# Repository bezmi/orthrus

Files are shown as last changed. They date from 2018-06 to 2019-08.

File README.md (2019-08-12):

# orthrus
56 key wireless split keyboard running on QMK. Staggered orthogonal layout

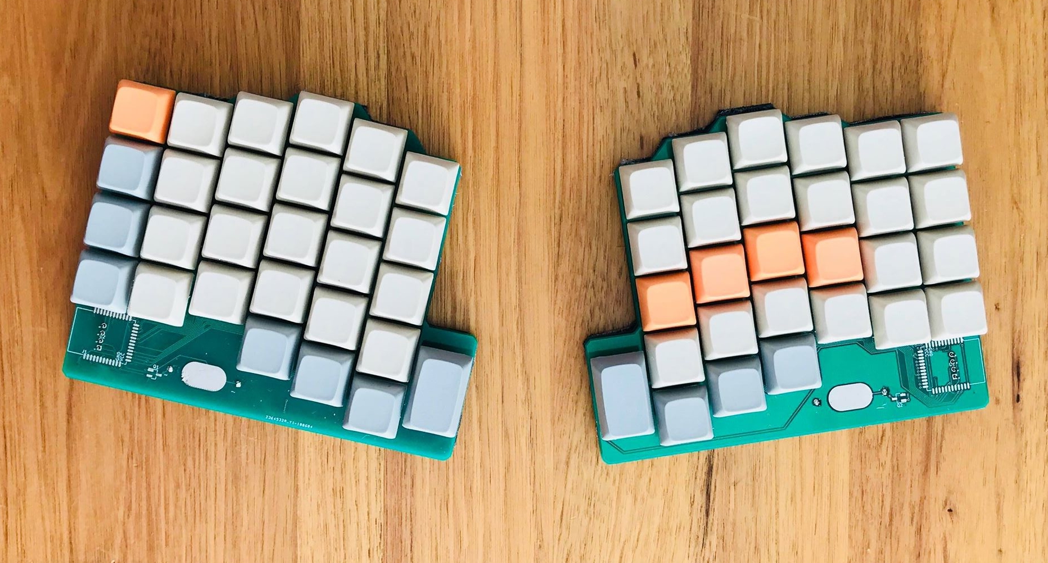
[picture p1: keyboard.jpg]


Refer to individual folders for help on the build, raise an issue if you need any extra help :)

To use with qmk, just merge the qmk_firmware/ directory in this repository with your downloaded qmk_firmware directory

# UPDATES

Over the time that I have been using this keyboard, the "sandwich" style battery holder has bee less than ideal. I have modified my keyboard with [these battery holders](https://au.rs-online.com/web/p/battery-holders-mounts/7188457/), which are epoxied to the top PCB for each half. The negative terminal of the battery holder is soldered to pad 3 "GND_P" on the top PCB with a short wire:

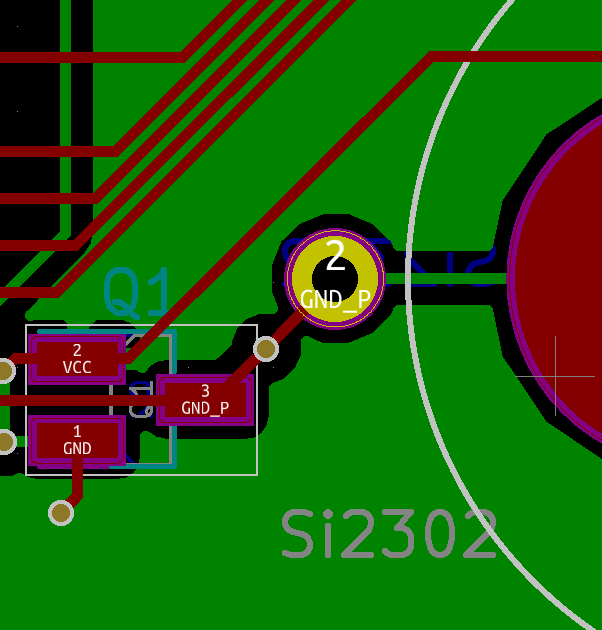
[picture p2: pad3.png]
Negative Terminal


The positive terminal is soldered to the through-hole VCC connection with a short wire:

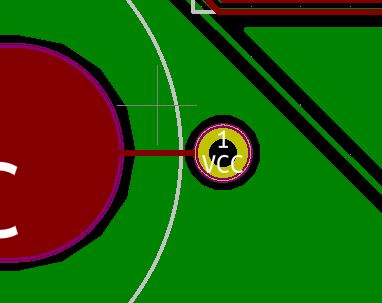
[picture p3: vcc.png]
Positive Terminal


This is what it looks like now.

Current image

# Acknowledgements
Thanks to [@reversebias](https://github.com/reversebias) for the inspiration as well as the firmware to make this work and [@joric](https://github.com/joric) for making the firmware work with the cheaper nrf modules

Thanks to technomancy for the original 42 key [atreus](https://atreus.technomancy.us) design and profet for the [atreus62](http://shop.profetkeyboards.com/product/atreus62-keyboard) design that I have been using for quite a while.

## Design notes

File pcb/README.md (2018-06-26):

# PCB

PCB design files and gerbers for the orthrus keyboard. See the [mitosis build log](https://imgur.com/a/mwTFj#JtzXTCD) for an overview of how to put this together.

There are a couple of minor differences. For example, for the programming header, my right angle connector footprint is too far in from the edge of the PCB, which resulted in the particular right angle headers I had not being reachable. I compromised by just using straight headers that go through the holes in the top (switch plate) pcb. It works just fine and the header is optional anyway. You could just as well solder temporary wires, program, then desolder before final assembly.

For the foam base, I did not have access to a lasercutter, so I cut a cloth mouse pad to size (including a cutout for the module on the bottom), cut all of the switch pins flush to the bottom of the PCB and hot glued the mousepad bits to the bottom. It is a little bumpy if you feel the bottom of the keyboard, but the typing feel is not compromised. Make sure you put tape on the module to avoid shorts!

For the receiver, I use the [mitosis receiver PCB](https://github.com/reversebias/mitosis-hardware). You can look at the BOM there (adjusting for extra switches, etc). I designed the PCBs to use the cheaper black nrf modules from aliexpress (Yj-14015), which are slightly smaller than the official waveshare module. For the receiver I had a legitimate waveshare module (blue) laying around, so I just used that, but soldering a Yj-14015 module to the receiver PCB can be very tricky. Feel free to extend the mitosis receiver pads and submit a pull request.

Make sure the PCB fab house can do 0.8mm slots. I've got mine manufactured from JLCPCB and the PCBs came out perfect.

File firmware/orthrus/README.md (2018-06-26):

# Mitosis Keyboard Firmware

This branch adds YJ-14015 and IAR support.

mitosis-mjt (https://www.youtube.com/watch?v=hMlQvZNmCc8)

It also makes use of the keyswitch board LED (it blinks two times on powering up to indicate that firmware works).

I'm using [modified QMK firmware](https://github.com/joric/qmk_firmware/blob/mitosis-joric/keyboards/mitosis/mitosis.c) (with mitosis-MJT keymap) that adds LED startup sequence to the receiver as well.

## Hardware

* [ST-LINK/V2](http://www.ebay.com/itm/ST-Link-V2-Programming-Unit-mini-STM8-STM32-Emulator-Downloader-M89-Top-/331803020521) (OpenOCD-compatible debugger/programmer)
* [YJ-14015](https://www.aliexpress.com/item/Core51822-BLE-4-0-Bluetooth-2-4G-Wireless-Module-NRF51822-Antenna-Board-For-ULP-SPI-I2C/32832872640.html) (nRF51822-module, 32-bit ARM Cortex M0, 128kB flash + 32kB RAM)
* PCB gerbers I used in this build: https://github.com/reversebias/mitosis-hardware

I've also collected a few Kicad ports from Altium: https://github.com/joric/mitosis-hardware/tree/joric_kicad

## Software

* [IAR 7.50.2 for ARM](https://www.iar.com/) (IDE that includes a C/C++ compiler)
* [nRF5_SDK_11](https://developer.nordicsemi.com/nRF5_SDK/) (nRF51/52 toolchain)
* [OpenOCD g73b676c](http://www.freddiechopin.info/en/download/category/10-openocd-dev/) (embedded debugger for Windows 10)
* [WinAVR 20100110](https://sourceforge.net/projects/winavr/) (firmware tools for AVR MCU)

## IAR support

Original build used blue Waveshare Core51822 (B)
modules ([$6.99](http://www.waveshare.com/core51822-b.htm)), but aliexpress has slightly smaller black YJ-14015
modules that are also much cheaper (about $3.50), you can find them on Aliexpress or [eBay](http://www.ebay.com/itm/BLE4-0-Bluetooth-2-4GHz-Wireless-Module-NRF51822-Board-Core51822-B-/282575577879).
It seems like stock firmware that works on Core51822 (B), doesn't work on YJ-14015 at all (update, already works, see https://github.com/reversebias/mitosis/pull/7).
You can build a working firmware in IAR, using provided project (open .eww, run build, that's all).
You may also use precompiled firmware from the `precompiled_iar` folder.

## GCC support

This repository now supports GCC for YJ-14015 as well, so there's no need for IAR.
Use GCC-prebuild firmware from the precompiled folder or apply this diff https://github.com/reversebias/mitosis/pull/7
(update: it's already merged into upstream).

## nRF51 Firmware

This firmware is used for the nRF51 modules on the keyboard halves and the receiver.

### Precompiled nRF51 Firmware

This precompiled firmware features YJ-14015 support and status LEDs support.

* left half: [precompiled-basic-left.hex](https://raw.githubusercontent.com/joric/mitosis/devel/precompiled_iar/precompiled-basic-left.hex)
* right half: [precompiled-basic-right.hex](https://raw.githubusercontent.com/joric/mitosis/devel/precompiled_iar/precompiled-basic-right.hex)
* receiver: [precompiled-basic-receiver.hex](https://raw.githubusercontent.com/joric/mitosis/devel/precompiled_iar/precompiled-basic-receiver.hex)

### Uploading nRF51 Firmware

To flash nRF modules, connect ST-LINK/V2 to the module programming pins (SWCLK, SWDIO, GND, 3.3V - top to bottom) and run this batch (windows 10):

```
@echo off
set path=C:\SDK\openocd-0.10.0-dev-00247-g73b676c\bin-x64;%path%
set file=%~dp0custom\iar\_build\nrf51822_xxac.hex
openocd ^
-f interface/stlink-v2.cfg ^
-f target/nrf51.cfg ^
-c init ^
-c "reset halt" ^
-c "flash write_image erase %file:\=/%" ^
-c "reset" ^
-c exit

```

### Building nRF51 Firmware

I am using Windows 10 and Windows Subsystem for Linux (WSL) for everything.

Building nRF firmware with GCC:

```
cd nRF5_SDK_11
git clone https://github.com/joric/mitosis
sudo apt install openocd gcc-arm-none-eabi
(edit /components/toolchain/gcc/Makefile.posix, set GNU_INSTALL_ROOT := /usr/)
sudo cp mitosis/49-stlinkv2.rules /etc/udev/rules.d/
cd mitosis
git checkout devel
cd mitosis-keyboard-basic/custom/armgcc
make

```

## QMK Firmware

This firmware is used for the Arduino Pro Micro on the keyboard receiver.

### Precompiled QMK Firmware

First of all, check [QMK repository](https://github.com/qmk/qmk_firmware/tree/master/keyboards/mitosis/keymaps) maybe your keymap is already merged.

* mitosis-default (original) from /u/reverse_bias: [kle](http://www.keyboard-layout-editor.com/#/gists/f89d2ff79b72e920939b), [keymap.c](https://github.com/qmk/qmk_firmware/blob/master/keyboards/mitosis/keymaps/default/keymap.c), [firmware](https://raw.githubusercontent.com/joric/qmk_firmware/mitosis-joric/precompiled/mitosis_default.hex), [pic](http://i.imgur.com/Ioh0Iix.png)
* mitosis-qwerty (qwerty layout) from /u/runninghack: [kle](http://www.keyboard-layout-editor.com/#/gists/acec41432b5ce0eb341d88245a20d9da), [keymap.c](https://github.com/runninghack/qmk_firmware/blob/master/keyboards/mitosis/keymaps/qwerty/keymap.c), [firmware](https://raw.githubusercontent.com/joric/qmk_firmware/mitosis-joric/precompiled/mitosis_qwerty.hex), [pic](https://i.imgur.com/Jt0lTWt.png)
* mitosis-mjt (qwerty layout) from /u/kaybeerry: [kle](http://www.keyboard-layout-editor.com/#/gists/e213fec721cb035614cef401cd6750d6), [keymap.c](https://github.com/mterhar/qmk_firmware/blob/master/keyboards/mitosis/keymaps/mjt/keymap.c), [firmware](https://raw.githubusercontent.com/joric/qmk_firmware/mitosis-joric/precompiled/mitosis_mjt.hex), [pic](https://i.imgur.com/BiKsnIV.png)
* mitosis-carvac_dv (qwerty layout) by /u/Carvac: [keymap.c](https://github.com/CarVac/qmk_firmware/blob/master/keyboards/mitosis/keymaps/carvac_dv/keymap.c)
* mitosis-workman (workman layout) by /u/mloffer: [kle](http://www.keyboard-layout-editor.com/#/gists/db73d647ad8a67c9654a4daeab0e0873), [keymap.c](https://github.com/mloffer/mitosis-workman)
* mitosis-atreus (atreus layout) from /u/iamjoric: [kle](http://www.keyboard-layout-editor.com/#/gists/e1b26b86c4e024d2f4f3185e5b769a00), [keymap.c](https://github.com/joric/qmk_firmware/blob/mitosis-joric/keyboards/mitosis/keymaps/atreus/keymap.c), [firmware](https://raw.githubusercontent.com/joric/qmk_firmware/mitosis-joric/precompiled/mitosis_atreus.hex)
* mitosis-joric (experimental) from /u/iamjoric: [kle](http://www.keyboard-layout-editor.com/#/gists/3f5dd1c848bb9a7a723161ad5e0c8e39), [keymap.c](https://github.com/joric/qmk_firmware/blob/mitosis-joric/keyboards/mitosis/keymaps/joric/keymap.c), [firmware](https://raw.githubusercontent.com/joric/qmk_firmware/mitosis-joric/precompiled/mitosis_joric.hex)

### Uploading QMK Firmware

To flash prebuilt QMK firmware on Pro Micro, press reset button on the receiver and run the script below.
You can look up the bootloader port in device manager (e.g. COM9), it shows only for a few seconds after reset.

```
set path=C:\WinAVR-20100110\bin;%path%
avrdude -p atmega32u4 -P COM9 -c avr109  -U flash:w:mitosis_default.hex
```

### Building QMK firmware:

```
sudo apt-get install gcc-avr avr-libc
cd qmk_firmware
make mitosis-default
```

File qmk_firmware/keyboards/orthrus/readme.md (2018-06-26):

Orthrus
=======

Keyboard Maintainer: [@bezmi](https://github.com/bezmi)
Hardware Supported: [Orthrus PCB](https://github.com/bezmi/orthrus)

Make example for this keyboard (run from root qmk_firmware directory)

    make orthrus:default:avrdude

See [build environment setup](https://docs.qmk.fm/build_environment_setup.html) then the [make instructions](https://docs.qmk.fm/make_instructions.html) for more information.

## Orthrus Notes

Files based off of the Mitosis keyboard. Uses a pro micro along with receiver PCB for wireless functionality.

Keyboard PCB design files can be found [here](https://github.com/bezmi/orthrus)
Receiver PCB is straight from the [mitosis](https://github.com/reversebias/mitosis-hardware)

Firmware for the nordic MCUs can be found [here](https://github.com/bezmi/orthrus)

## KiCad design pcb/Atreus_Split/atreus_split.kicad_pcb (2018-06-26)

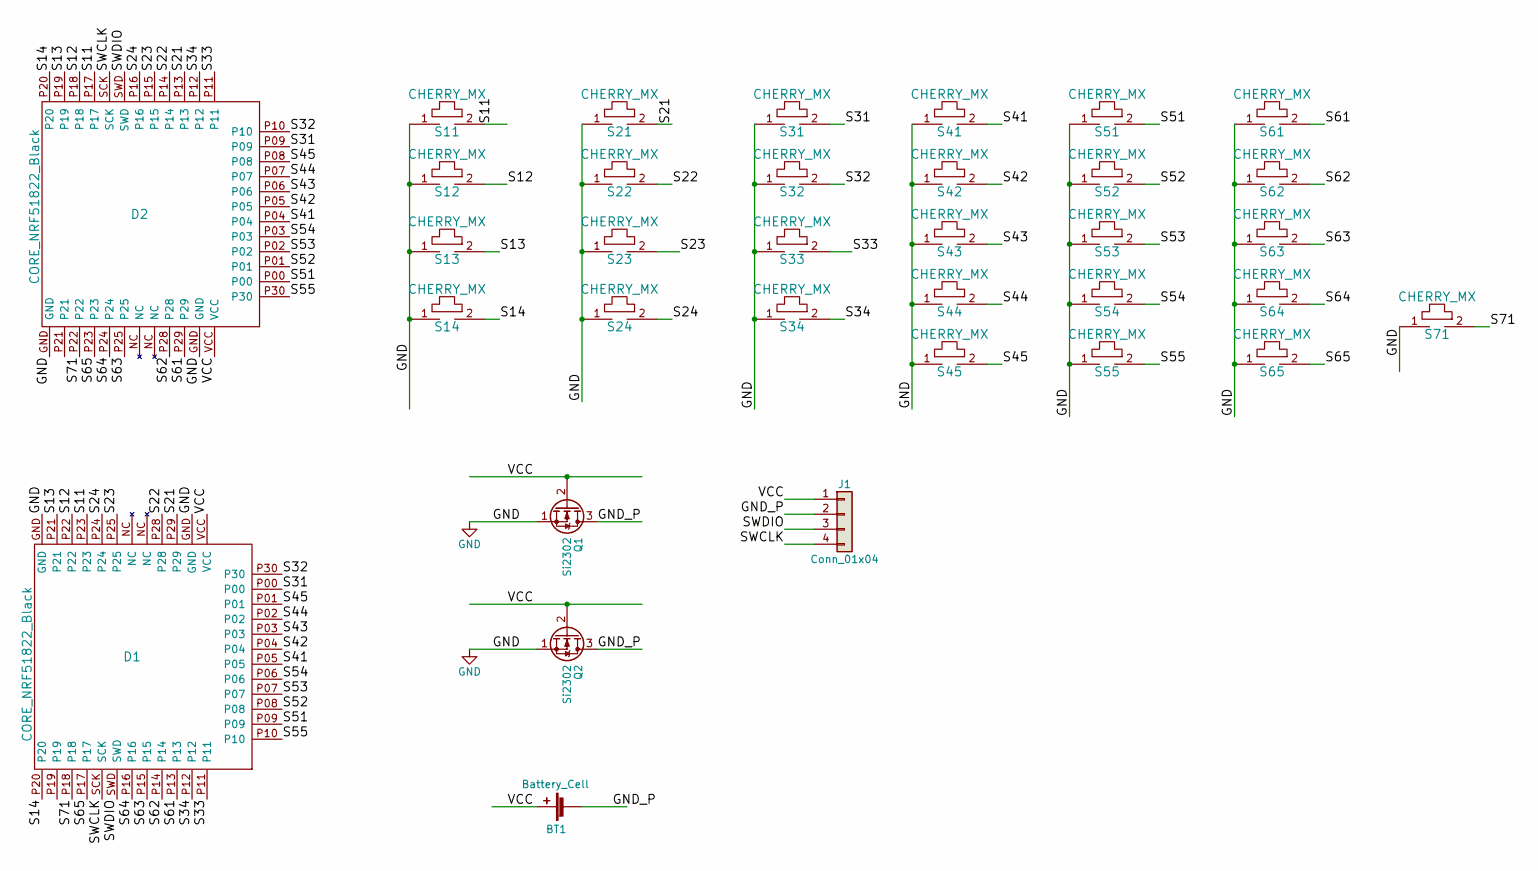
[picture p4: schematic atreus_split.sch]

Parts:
BT1: Battery_Cell; CR2032_pad
D1, D2: CORE_NRF51822_Black
J1: Conn_01x04; Pin_Header_Angled_1x04_Pitch2.54mm
Q1, Q2: Si2302; SI2302
S11, S12, S13, S14, S21, S22, S23, S24, S31, S32, S33, S34, S41, S42, S43, S44, S45, S51, S52, S53, S54, S55, S61, S62, S63, S64, S65, S71: CHERRY_MX; cherry

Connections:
/GND_P: BT1.2 (-), J1.2, Q1.3 (D), Q2.3 (D)
/S11: D1.P23, D2.P17, S11.2
/S12: D1.P22, D2.P18, S12.2
/S13: D1.P21, D2.P19, S13.2
/S14: D1.P20, D2.P20, S14.2
/S21: D1.P29, D2.P13, S21.2
/S22: D1.P28, D2.P14, S22.2
/S23: D1.P25, D2.P15, S23.2
/S24: D1.P24, D2.P16, S24.2
/S31: D1.P00, D2.P09, S31.2
/S32: D1.P30, D2.P10, S32.2
/S33: D1.P11, D2.P11, S33.2
/S34: D1.P12, D2.P12, S34.2
/S41: D1.P05, D2.P04, S41.2
/S42: D1.P04, D2.P05, S42.2
/S43: D1.P03, D2.P06, S43.2
/S44: D1.P02, D2.P07, S44.2
/S45: D1.P01, D2.P08, S45.2
/S51: D1.P09, D2.P00, S51.2
/S52: D1.P08, D2.P01, S52.2
/S53: D1.P07, D2.P02, S53.2
/S54: D1.P06, D2.P03, S54.2
/S55: D1.P10, D2.P30, S55.2
/S61: D1.P13, D2.P29, S61.2
/S62: D1.P14, D2.P28, S62.2
/S63: D1.P15, D2.P25, S63.2
/S64: D1.P16, D2.P24, S64.2
/S65: D1.P17, D2.P23, S65.2
/S71: D1.P18, D2.P22, S71.2
/SWCLK: D1.SCK, D2.SCK, J1.4
/SWDIO: D1.SWD, D2.SWD, J1.3
/VCC: BT1.1 (+), D1.VCC, D2.VCC, J1.1, Q1.2 (G), Q2.2 (G)
GND: D1.GND, D2.GND, Q1.1 (S), Q2.1 (S), S11.1, S12.1, S13.1, S14.1, S21.1, S22.1, S23.1, S24.1, S31.1, S32.1, S33.1, S34.1, S41.1, S42.1, S43.1, S44.1, S45.1, S51.1, S52.1, S53.1, S54.1, S55.1, S61.1, S62.1, S63.1, S64.1, S65.1, S71.1

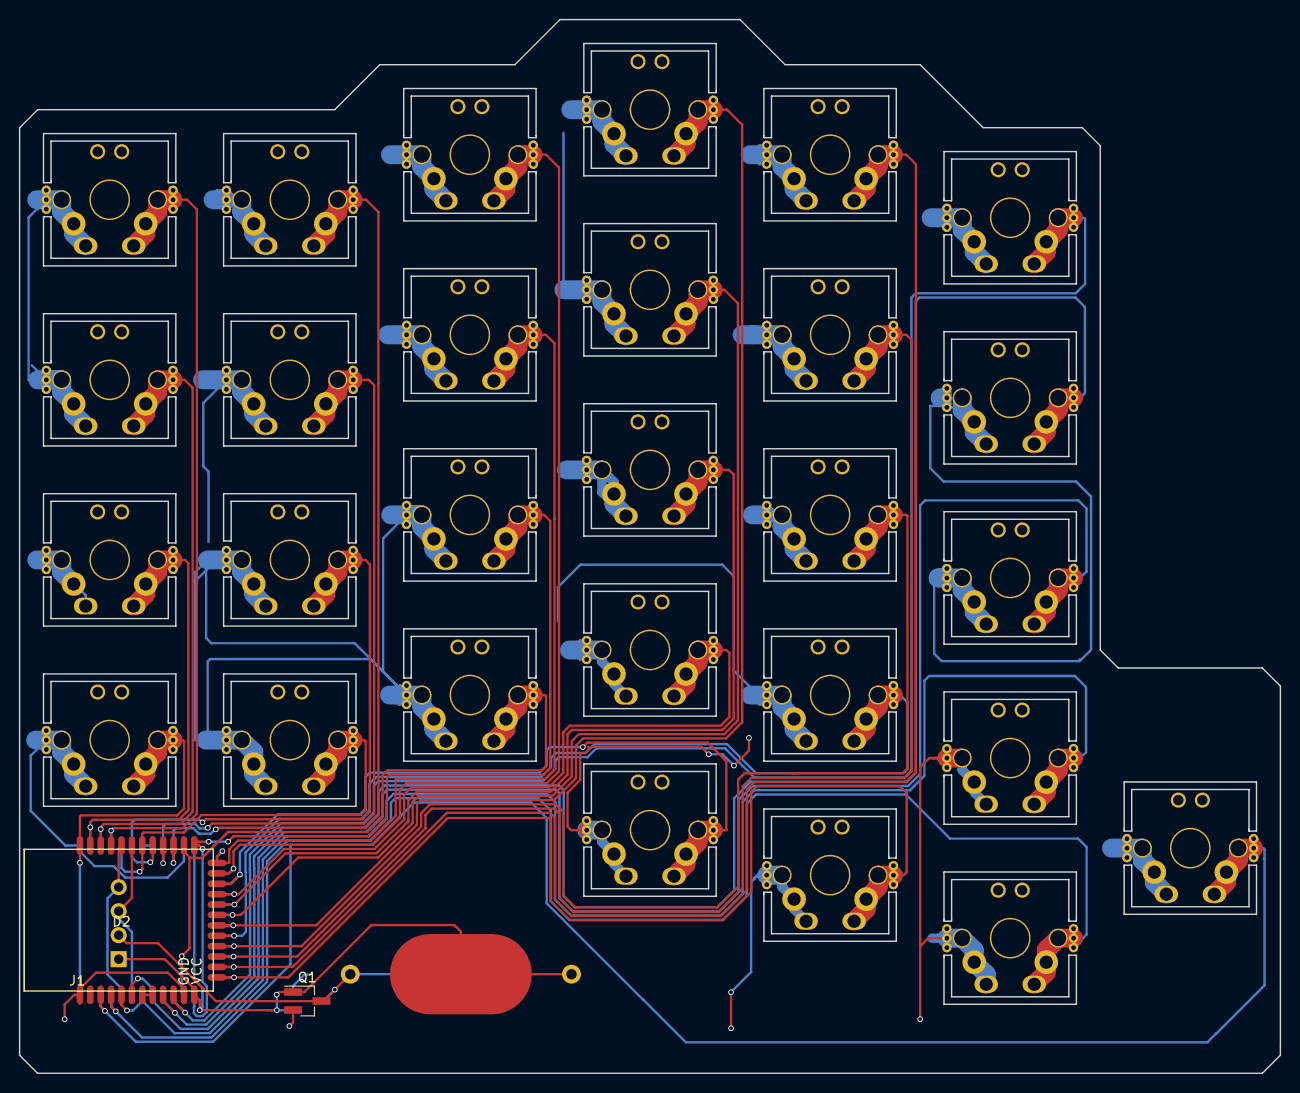
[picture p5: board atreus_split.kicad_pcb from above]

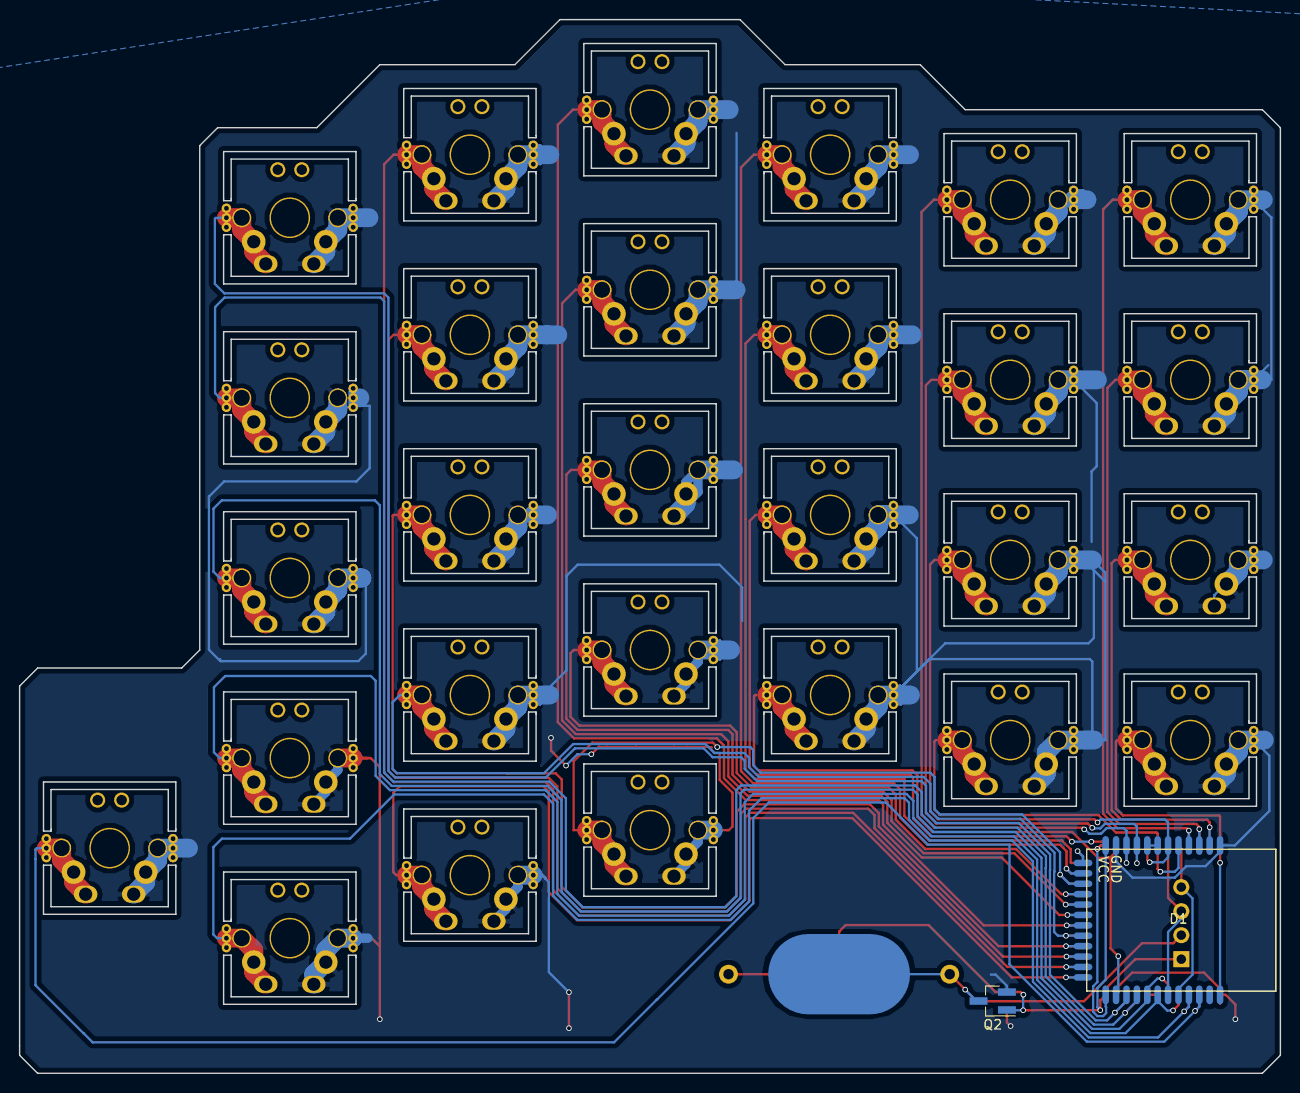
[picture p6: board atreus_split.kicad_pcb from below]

Board: 2 copper layers, 133.4 x 111.4 mm, 34 parts (2 on the bottom side), 33 nets.

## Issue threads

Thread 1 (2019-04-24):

ST-Link V2 programmer shuts off when attaching to keyboard PCB

Peping, 2019-04-24:
**CONTENT WARNING: copious amounts of rosin in pics below**
First of all, thanks for making this keyboard available. It's been an amazing, albeit very long journey getting all parts and fitting everything together.

However I got stuck trying to program the keyboard PCBs. Whenever I try to connect my ST-Link V2 to the header, it just shuts off as if it had come across a short or something.

Now I have practically no knowledge of electronics, but I have tested for shorts between all the header pins and there isn't one. I then tried to test for continuity between header ground and Yj-14015 module ground, I got some voltage drop, but still continuity. I suspect the voltage drop is due to the transistor and is normal.

Speaking of, you moved the FET slightly as opposed to Mitosis, which raises my doubts about whether I soldered it on the right side. Could you check my photos? Could you please also check for anything I might've missed that could cause my programmer to freak out?

All photos are of the to-be right half of the keyboard:
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

__________________________________
For right angle headers I instead used straight headers and connected them via a solder bridge

bezmi, 2019-04-26:
That is exactly how I have the FET soldered, so I am not sure what is causing your issue. You can try desoldering the FET and bridging the bottom left (source) and right (drain) pad - here is the [pinout](https://www.datasheetq.com/image/MCC/607347.gif). This should bypass the reverse polarity protection and allow you to power the module directly. Make sure you only apply the 3.3V.

You can also try some continuity checking. In a [reverse polarity protection circuit](url) with an n-channel FET, the negative of the battery should be connected to the drain, the ground of the circuit (GND pin on module) should be connected to the source and the gate should be connected to both the positive terminal of the battery and the VCC pin on the module.

Peping, 2019-04-26:
Thanks for the tip. I will try bridging the pads. Jut a quick question: Do I have to have the battery connected in order to connect the programmer?

bezmi, 2019-04-26:
No, leave the battery disconnected and power it via the 3.3V on the programmer. The pinout of the header from bottom to top is:

1. 3.3V
2. GND
3. SWDIO
4. SWCLK

Peping, 2019-04-28:
Bridging the pads made it so that the programmer's indicator (the blue LED) would stay on. Before, it would turn of the moment I connected GND and VDD. But with the bridged FET pads, as you suggested, I still couldn't connect to the chip via OCD.
```
Open On-Chip Debugger 0.10.0
Licensed under GNU GPL v2
For bug reports, read
	http://openocd.org/doc/doxygen/bugs.html
Info : The selected transport took over low-level target control. The results might differ compared to plain JTAG/SWD
adapter speed: 1000 kHz
Info : Unable to match requested speed 1000 kHz, using 950 kHz
Info : Unable to match requested speed 1000 kHz, using 950 kHz
Info : clock speed 950 kHz
Info : STLINK v2 JTAG v17 API v2 SWIM v4 VID 0x0483 PID 0x3748
Info : using stlink api v2
Info : Target voltage: 3.211556
Error: init mode failed (unable to connect to the target)
in procedure 'init'
in procedure 'ocd_bouncer'
```

In a desperate attempt involving lots of continuity checking and misinterpreting the results, I left the FET pads unconnected. Strapping the programmer to the board in this state (no FET, no bridge, nothing) allowed OpenOCD to connect, or at least that's what I thought. When I tried flashing it, it failed.

```
Open On-Chip Debugger 0.10.0
Licensed under GNU GPL v2
For bug reports, read
	http://openocd.org/doc/doxygen/bugs.html
Info : The selected transport took over low-level target control. The results might differ compared to plain JTAG/SWD
adapter speed: 1000 kHz
Info : Unable to match requested speed 1000 kHz, using 950 kHz
Info : Unable to match requested speed 1000 kHz, using 950 kHz
Info : clock speed 950 kHz
Info : STLINK v2 JTAG v17 API v2 SWIM v4 VID 0x0483 PID 0x3748
Info : using stlink api v2
Info : Target voltage: 3.200525
Info : nrf51.cpu: hardware has 4 breakpoints, 2 watchpoints
Info : accepting 'telnet' connection on tcp/4444
target halted due to debug-request, current mode: Thread
xPSR: 0xc1000000 pc: 0xfffffffe msp: 0xfffffffc
Warn : Unknown device (HWID 0x000000d1)
Error: Failed to enable read-only operation
Error: Failed to erase reg: 0x4001e508 val: 0x00000000
Error: Failed to erase sector @ 0x00000000
Error: Failed to write to nrf51 flash
Error: error writing to flash at address 0x00000000 at offset 0x00000000

Info : dropped 'telnet' connection
Error: jtag status contains invalid mode value - communication failure
Polling target nrf51.cpu failed, trying to reexamine
Examination failed, GDB will be halted. Polling again in 100ms
Info : Previous state query failed, trying to reconnect
Polling target nrf51.cpu failed, trying to reexamine
Info : nrf51.cpu: hardware has 4 breakpoints, 2 watchpoints
```

As a sanity check, I soldered the same chip to a spare mitosis receiver board and tried programming it there. That completed successfully. So the chips aren't bad. It must be something about the boards or how I soldered them.

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

bezmi, 2019-04-28:
> no FET, no bridge, nothing

In this case there is no path to ground and there should be no continuity between the NRF51 GND pin and the GND pin on the programming header. I am surprised you managed to power up and connect to the NRF module in this state. Can you please check continuity between the GND pin on the header and the GND pin of the NRF51 (without the programmer connected)?

Other than that, there should be nothing wrong with PCB, especially when you short out the GND and GND_P pads on the "top" side of the board (NRF module is on the bottom).

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

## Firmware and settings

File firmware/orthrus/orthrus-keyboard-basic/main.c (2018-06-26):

#define COMPILE_RIGHT
/*#define COMPILE_LEFT*/

#include "mitosis.h"
#include "nrf_drv_config.h"
#include "nrf_gzll.h"
#include "nrf_gpio.h"
#include "nrf_delay.h"
#include "nrf_drv_clock.h"
#include "nrf_drv_rtc.h"


/*****************************************************************************/
/** Configuration */
/*****************************************************************************/

const nrf_drv_rtc_t rtc_maint = NRF_DRV_RTC_INSTANCE(0); /**< Declaring an instance of nrf_drv_rtc for RTC0. */
const nrf_drv_rtc_t rtc_deb = NRF_DRV_RTC_INSTANCE(1); /**< Declaring an instance of nrf_drv_rtc for RTC1. */


// Define payload length
#define TX_PAYLOAD_LENGTH 4 ///< 3 byte payload length when transmitting

// Data and acknowledgement payloads
static uint8_t data_payload[TX_PAYLOAD_LENGTH];                ///< Payload to send to Host. 
static uint8_t ack_payload[NRF_GZLL_CONST_MAX_PAYLOAD_LENGTH]; ///< Placeholder for received ACK payloads from Host.

// Debounce time (dependent on tick frequency)
#define DEBOUNCE 5
#define ACTIVITY 500

// Key buffers
static uint32_t keys, keys_snapshot;
static uint32_t debounce_ticks, activity_ticks;
static volatile bool debouncing = false;

// Debug helper variables
static volatile bool init_ok, enable_ok, push_ok, pop_ok, tx_success;  

// Setup switch pins with pullups
static void gpio_config(void)
{
    nrf_gpio_cfg_sense_input(S11, NRF_GPIO_PIN_PULLUP, NRF_GPIO_PIN_SENSE_LOW);
    nrf_gpio_cfg_sense_input(S12, NRF_GPIO_PIN_PULLUP, NRF_GPIO_PIN_SENSE_LOW);
    nrf_gpio_cfg_sense_input(S13, NRF_GPIO_PIN_PULLUP, NRF_GPIO_PIN_SENSE_LOW);
    nrf_gpio_cfg_sense_input(S14, NRF_GPIO_PIN_PULLUP, NRF_GPIO_PIN_SENSE_LOW);
    nrf_gpio_cfg_sense_input(S21, NRF_GPIO_PIN_PULLUP, NRF_GPIO_PIN_SENSE_LOW);
    nrf_gpio_cfg_sense_input(S22, NRF_GPIO_PIN_PULLUP, NRF_GPIO_PIN_SENSE_LOW);
    nrf_gpio_cfg_sense_input(S23, NRF_GPIO_PIN_PULLUP, NRF_GPIO_PIN_SENSE_LOW);
    nrf_gpio_cfg_sense_input(S24, NRF_GPIO_PIN_PULLUP, NRF_GPIO_PIN_SENSE_LOW);
    nrf_gpio_cfg_sense_input(S31, NRF_GPIO_PIN_PULLUP, NRF_GPIO_PIN_SENSE_LOW);
    nrf_gpio_cfg_sense_input(S32, NRF_GPIO_PIN_PULLUP, NRF_GPIO_PIN_SENSE_LOW);
    nrf_gpio_cfg_sense_input(S33, NRF_GPIO_PIN_PULLUP, NRF_GPIO_PIN_SENSE_LOW);
    nrf_gpio_cfg_sense_input(S34, NRF_GPIO_PIN_PULLUP, NRF_GPIO_PIN_SENSE_LOW);
    nrf_gpio_cfg_sense_input(S41, NRF_GPIO_PIN_PULLUP, NRF_GPIO_PIN_SENSE_LOW);
    nrf_gpio_cfg_sense_input(S42, NRF_GPIO_PIN_PULLUP, NRF_GPIO_PIN_SENSE_LOW);
    nrf_gpio_cfg_sense_input(S43, NRF_GPIO_PIN_PULLUP, NRF_GPIO_PIN_SENSE_LOW);
    nrf_gpio_cfg_sense_input(S44, NRF_GPIO_PIN_PULLUP, NRF_GPIO_PIN_SENSE_LOW);
    nrf_gpio_cfg_sense_input(S45, NRF_GPIO_PIN_PULLUP, NRF_GPIO_PIN_SENSE_LOW);
    nrf_gpio_cfg_sense_input(S51, NRF_GPIO_PIN_PULLUP, NRF_GPIO_PIN_SENSE_LOW);
    nrf_gpio_cfg_sense_input(S52, NRF_GPIO_PIN_PULLUP, NRF_GPIO_PIN_SENSE_LOW);
    nrf_gpio_cfg_sense_input(S53, NRF_GPIO_PIN_PULLUP, NRF_GPIO_PIN_SENSE_LOW);
    nrf_gpio_cfg_sense_input(S54, NRF_GPIO_PIN_PULLUP, NRF_GPIO_PIN_SENSE_LOW);
    nrf_gpio_cfg_sense_input(S55, NRF_GPIO_PIN_PULLUP, NRF_GPIO_PIN_SENSE_LOW);
    nrf_gpio_cfg_sense_input(S61, NRF_GPIO_PIN_PULLUP, NRF_GPIO_PIN_SENSE_LOW);
    nrf_gpio_cfg_sense_input(S62, NRF_GPIO_PIN_PULLUP, NRF_GPIO_PIN_SENSE_LOW);
    nrf_gpio_cfg_sense_input(S63, NRF_GPIO_PIN_PULLUP, NRF_GPIO_PIN_SENSE_LOW);
    nrf_gpio_cfg_sense_input(S64, NRF_GPIO_PIN_PULLUP, NRF_GPIO_PIN_SENSE_LOW);
    nrf_gpio_cfg_sense_input(S65, NRF_GPIO_PIN_PULLUP, NRF_GPIO_PIN_SENSE_LOW);
    nrf_gpio_cfg_sense_input(S71, NRF_GPIO_PIN_PULLUP, NRF_GPIO_PIN_SENSE_LOW);
}

// Return the key states, masked with valid key pins
static uint32_t read_keys(void)
{
    return ~NRF_GPIO->IN & INPUT_MASK;
}

// Assemble packet and send to receiver
static void send_data(void)
{
    data_payload[0] = ((keys & 1<<S11) ? 1:0) << 7 | \
                      ((keys & 1<<S21) ? 1:0) << 6 | \
                      ((keys & 1<<S31) ? 1:0) << 5 | \
                      ((keys & 1<<S41) ? 1:0) << 4 | \
                      ((keys & 1<<S51) ? 1:0) << 3 | \
                      ((keys & 1<<S61) ? 1:0) << 2 | \
                      ((keys & 1<<S12) ? 1:0) << 1 | \
                      ((keys & 1<<S22) ? 1:0) << 0;

    data_payload[1] = ((keys & 1<<S32) ? 1:0) << 7 | \
                      ((keys & 1<<S42) ? 1:0) << 6 | \
                      ((keys & 1<<S52) ? 1:0) << 5 | \
                      ((keys & 1<<S62) ? 1:0) << 4 | \
                      ((keys & 1<<S13) ? 1:0) << 3 | \
                      ((keys & 1<<S23) ? 1:0) << 2 | \
                      ((keys & 1<<S33) ? 1:0) << 1 | \
                      ((keys & 1<<S43) ? 1:0) << 0;

    data_payload[2] = ((keys & 1<<S53) ? 1:0) << 7 | \
                      ((keys & 1<<S63) ? 1:0) << 6 | \
                      ((keys & 1<<S14) ? 1:0) << 5 | \
                      ((keys & 1<<S24) ? 1:0) << 4 | \
                      ((keys & 1<<S34) ? 1:0) << 3 | \
                      ((keys & 1<<S44) ? 1:0) << 2 | \
                      ((keys & 1<<S54) ? 1:0) << 1 | \
                      ((keys & 1<<S64) ? 1:0) << 0;

    data_payload[3] = ((keys & 1<<S45) ? 1:0) << 7 | \
                      ((keys & 1<<S55) ? 1:0) << 6 | \
                      ((keys & 1<<S65) ? 1:0) << 5 | \
                      ((keys & 1<<S71) ? 1:0) << 4 | \
                      0 << 0 | \
                      0 << 0 | \
                      0 << 0 | \
                      0 << 0;
    nrf_gzll_add_packet_to_tx_fifo(PIPE_NUMBER, data_payload, TX_PAYLOAD_LENGTH);
}

// 8Hz held key maintenance, keeping the reciever keystates valid
static void handler_maintenance(nrf_drv_rtc_int_type_t int_type)
{
    send_data();
}

// 1000Hz debounce sampling
static void handler_debounce(nrf_drv_rtc_int_type_t int_type)
{
    // debouncing, waits until there have been no transitions in 5ms (assuming five 1ms ticks)
    if (debouncing)
    {
        // if debouncing, check if current keystates equal to the snapshot
        if (keys_snapshot == read_keys())
        {
            // DEBOUNCE ticks of stable sampling needed before sending data
            debounce_ticks++;
            if (debounce_ticks == DEBOUNCE)
            {
                keys = keys_snapshot;
                send_data();
            }
        }
        else
        {
            // if keys change, start period again
            debouncing = false;
        }
    }
    else
    {
        // if the keystate is different from the last data
        // sent to the receiver, start debouncing
        if (keys != read_keys())
        {
            keys_snapshot = read_keys();
            debouncing = true;
            debounce_ticks = 0;
        }
    }

    // looking for 500 ticks of no keys pressed, to go back to deep sleep
    if (read_keys() == 0)
    {
        activity_ticks++;
        if (activity_ticks > ACTIVITY)
        {
            nrf_drv_rtc_disable(&rtc_maint);
            nrf_drv_rtc_disable(&rtc_deb);
        }
    }
    else
    {
        activity_ticks = 0;
    }

}


// Low frequency clock configuration
static void lfclk_config(void)
{
    nrf_drv_clock_init();

    nrf_drv_clock_lfclk_request(NULL);
}

// RTC peripheral configuration
static void rtc_config(void)
{
    //Initialize RTC instance
    nrf_drv_rtc_init(&rtc_maint, NULL, handler_maintenance);
    nrf_drv_rtc_init(&rtc_deb, NULL, handler_debounce);

    //Enable tick event & interrupt
    nrf_drv_rtc_tick_enable(&rtc_maint,true);
    nrf_drv_rtc_tick_enable(&rtc_deb,true);

    //Power on RTC instance
    //nrf_drv_rtc_enable(&rtc_maint);
    //nrf_drv_rtc_enable(&rtc_deb);
}

int main()
{
    // Initialize Gazell
    nrf_gzll_init(NRF_GZLL_MODE_DEVICE);
    
    // Attempt sending every packet up to 100 times    
    nrf_gzll_set_max_tx_attempts(100);

    // Addressing
    nrf_gzll_set_base_address_0(0x01020304);
    nrf_gzll_set_base_address_1(0x05060708);

    // Enable Gazell to start sending over the air
    nrf_gzll_enable();

    // Configure 32kHz xtal oscillator
    lfclk_config(); 

    // Configure RTC peripherals with ticks
    rtc_config();

    // Configure all keys as inputs with pullups
    gpio_config();

    // Set the GPIOTE PORT event as interrupt source, and enable interrupts for GPIOTE
    NRF_GPIOTE->INTENSET = GPIOTE_INTENSET_PORT_Msk;
    NVIC_EnableIRQ(GPIOTE_IRQn);
    
    /*nrf_gpio_cfg_output(LED_PIN);*/
    /*nrf_gpio_pin_set(LED_PIN);*/
    /*nrf_delay_ms(250);*/
    /*nrf_gpio_pin_clear(LED_PIN);*/
    /*nrf_delay_ms(250);*/
    /*nrf_gpio_pin_set(LED_PIN);*/
    /*nrf_delay_ms(250);*/
    /*nrf_gpio_pin_clear(LED_PIN);*/


    // Main loop, constantly sleep, waiting for RTC and gpio IRQs
    while(1)
    {
        __SEV();
        __WFE();
        __WFE(); 
    }
}

// This handler will be run after wakeup from system ON (GPIO wakeup)
void GPIOTE_IRQHandler(void)
{
    if(NRF_GPIOTE->EVENTS_PORT)
    {
        //clear wakeup event
        NRF_GPIOTE->EVENTS_PORT = 0;

        //enable rtc interupt triggers
        nrf_drv_rtc_enable(&rtc_maint);
        nrf_drv_rtc_enable(&rtc_deb);

        debouncing = false;
        debounce_ticks = 0;
        activity_ticks = 0;
    }
}



/*****************************************************************************/
/** Gazell callback function definitions  */
/*****************************************************************************/

void  nrf_gzll_device_tx_success(uint32_t pipe, nrf_gzll_device_tx_info_t tx_info)
{
    uint32_t ack_payload_length = NRF_GZLL_CONST_MAX_PAYLOAD_LENGTH;    

    if (tx_info.payload_received_in_ack)
    {
        // Pop packet and write first byte of the payload to the GPIO port.
        nrf_gzll_fetch_packet_from_rx_fifo(pipe, ack_payload, &ack_payload_length);
    }
}

// no action is taken when a packet fails to send, this might need to change
void nrf_gzll_device_tx_failed(uint32_t pipe, nrf_gzll_device_tx_info_t tx_info)
{
    
}

// Callbacks not needed
void nrf_gzll_host_rx_data_ready(uint32_t pipe, nrf_gzll_host_rx_info_t rx_info)
{}
void nrf_gzll_disabled()
{}

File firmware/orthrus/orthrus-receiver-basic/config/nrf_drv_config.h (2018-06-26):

/* Copyright (c) 2015 Nordic Semiconductor. All Rights Reserved.
 *
 * The information contained herein is property of Nordic Semiconductor ASA.
 * Terms and conditions of usage are described in detail in NORDIC
 * SEMICONDUCTOR STANDARD SOFTWARE LICENSE AGREEMENT.
 *
 * Licensees are granted free, non-transferable use of the information. NO
 * WARRANTY of ANY KIND is provided. This heading must NOT be removed from
 * the file.
 *
 */

#ifndef NRF_DRV_CONFIG_H
#define NRF_DRV_CONFIG_H

/**
 * Provide a non-zero value here in applications that need to use several
 * peripherals with the same ID that are sharing certain resources
 * (for example, SPI0 and TWI0). Obviously, such peripherals cannot be used
 * simultaneously. Therefore, this definition allows to initialize the driver
 * for another peripheral from a given group only after the previously used one
 * is uninitialized. Normally, this is not possible, because interrupt handlers
 * are implemented in individual drivers.
 * This functionality requires a more complicated interrupt handling and driver
 * initialization, hence it is not always desirable to use it.
 */
#define PERIPHERAL_RESOURCE_SHARING_ENABLED  0

/* CLOCK */
#define CLOCK_ENABLED 1

#if (CLOCK_ENABLED == 1)
#define CLOCK_CONFIG_XTAL_FREQ          NRF_CLOCK_XTALFREQ_Default
#define CLOCK_CONFIG_LF_SRC             NRF_CLOCK_LFCLK_Xtal
#define CLOCK_CONFIG_IRQ_PRIORITY       APP_IRQ_PRIORITY_LOW
#endif

/* GPIOTE */
#define GPIOTE_ENABLED 0

#if (GPIOTE_ENABLED == 1)
#define GPIOTE_CONFIG_USE_SWI_EGU false
#define GPIOTE_CONFIG_IRQ_PRIORITY APP_IRQ_PRIORITY_LOW
#define GPIOTE_CONFIG_NUM_OF_LOW_POWER_EVENTS 1
#endif

/* TIMER */
#define TIMER0_ENABLED 0

#if (TIMER0_ENABLED == 1)
#define TIMER0_CONFIG_FREQUENCY    NRF_TIMER_FREQ_16MHz
#define TIMER0_CONFIG_MODE         TIMER_MODE_MODE_Timer
#define TIMER0_CONFIG_BIT_WIDTH    TIMER_BITMODE_BITMODE_32Bit
#define TIMER0_CONFIG_IRQ_PRIORITY APP_IRQ_PRIORITY_LOW

#define TIMER0_INSTANCE_INDEX      0
#endif

#define TIMER1_ENABLED 0

#if (TIMER1_ENABLED == 1)
#define TIMER1_CONFIG_FREQUENCY    NRF_TIMER_FREQ_16MHz
#define TIMER1_CONFIG_MODE         TIMER_MODE_MODE_Timer
#define TIMER1_CONFIG_BIT_WIDTH    TIMER_BITMODE_BITMODE_16Bit
#define TIMER1_CONFIG_IRQ_PRIORITY APP_IRQ_PRIORITY_LOW

#define TIMER1_INSTANCE_INDEX      (TIMER0_ENABLED)
#endif
 
#define TIMER2_ENABLED 0

#if (TIMER2_ENABLED == 1)
#define TIMER2_CONFIG_FREQUENCY    NRF_TIMER_FREQ_16MHz
#define TIMER2_CONFIG_MODE         TIMER_MODE_MODE_Timer
#define TIMER2_CONFIG_BIT_WIDTH    TIMER_BITMODE_BITMODE_16Bit
#define TIMER2_CONFIG_IRQ_PRIORITY APP_IRQ_PRIORITY_LOW

#define TIMER2_INSTANCE_INDEX      (TIMER1_ENABLED+TIMER0_ENABLED)
#endif

#define TIMER3_ENABLED 0

#if (TIMER3_ENABLED == 1)
#define TIMER3_CONFIG_FREQUENCY    NRF_TIMER_FREQ_16MHz
#define TIMER3_CONFIG_MODE         TIMER_MODE_MODE_Timer
#define TIMER3_CONFIG_BIT_WIDTH    TIMER_BITMODE_BITMODE_16Bit
#define TIMER3_CONFIG_IRQ_PRIORITY APP_IRQ_PRIORITY_LOW

#define TIMER3_INSTANCE_INDEX      (TIMER2_ENABLED+TIMER1_ENABLED+TIMER0_ENABLED)
#endif

#define TIMER4_ENABLED 0

#if (TIMER4_ENABLED == 1)
#define TIMER4_CONFIG_FREQUENCY    NRF_TIMER_FREQ_16MHz
#define TIMER4_CONFIG_MODE         TIMER_MODE_MODE_Timer
#define TIMER4_CONFIG_BIT_WIDTH    TIMER_BITMODE_BITMODE_16Bit
#define TIMER4_CONFIG_IRQ_PRIORITY APP_IRQ_PRIORITY_LOW

#define TIMER4_INSTANCE_INDEX      (TIMER3_ENABLED+TIMER2_ENABLED+TIMER1_ENABLED+TIMER0_ENABLED)
#endif


#define TIMER_COUNT (TIMER0_ENABLED + TIMER1_ENABLED + TIMER2_ENABLED + TIMER3_ENABLED + TIMER4_ENABLED)

/* RTC */
#define RTC0_ENABLED 1

#if (RTC0_ENABLED == 1)
#define RTC0_CONFIG_FREQUENCY    32678
#define RTC0_CONFIG_IRQ_PRIORITY APP_IRQ_PRIORITY_LOW
#define RTC0_CONFIG_RELIABLE     false

#define RTC0_INSTANCE_INDEX      0
#endif

#define RTC1_ENABLED 0

#if (RTC1_ENABLED == 1)
#define RTC1_CONFIG_FREQUENCY    32768
#define RTC1_CONFIG_IRQ_PRIORITY APP_IRQ_PRIORITY_LOW
#define RTC1_CONFIG_RELIABLE     false

#define RTC1_INSTANCE_INDEX      (RTC0_ENABLED)
#endif

#define RTC2_ENABLED 0

#if (RTC2_ENABLED == 1)
#define RTC2_CONFIG_FREQUENCY    32768
#define RTC2_CONFIG_IRQ_PRIORITY APP_IRQ_PRIORITY_LOW
#define RTC2_CONFIG_RELIABLE     false

#define RTC2_INSTANCE_INDEX      (RTC0_ENABLED+RTC1_ENABLED)
#endif


#define RTC_COUNT                (RTC0_ENABLED+RTC1_ENABLED+RTC2_ENABLED)

#define NRF_MAXIMUM_LATENCY_US 2000

/* RNG */
#define RNG_ENABLED 0

#if (RNG_ENABLED == 1)
#define RNG_CONFIG_ERROR_CORRECTION true
#define RNG_CONFIG_POOL_SIZE        8
#define RNG_CONFIG_IRQ_PRIORITY     APP_IRQ_PRIORITY_LOW
#endif

/* PWM */

#define PWM0_ENABLED 0
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

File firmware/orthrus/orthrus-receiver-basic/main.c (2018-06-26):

#include <stdbool.h>
#include <stdint.h>
#include <stdio.h>
#include "app_uart.h"
#include "nrf_drv_uart.h"
#include "app_error.h"
#include "nrf_delay.h"
#include "nrf.h"
#include "nrf_gzll.h"

#define MAX_TEST_DATA_BYTES     (15U)                /**< max number of test bytes to be used for tx and rx. */
#define UART_TX_BUF_SIZE 256                         /**< UART TX buffer size. */
#define UART_RX_BUF_SIZE 1                           /**< UART RX buffer size. */


#define RX_PIN_NUMBER  25
#define TX_PIN_NUMBER  24
#define CTS_PIN_NUMBER 23
#define RTS_PIN_NUMBER 22
#define HWFC           false


// Define payload length
#define TX_PAYLOAD_LENGTH 4 ///< 4 byte payload length

// ticks for inactive keyboard
#define INACTIVE 100000

// Binary printing
#define BYTE_TO_BINARY_PATTERN "%c%c%c%c%c"
#define BYTE_TO_BINARY(byte)  \
  (byte & 0x10 ? '#' : '.'), \
  (byte & 0x08 ? '#' : '.'), \
  (byte & 0x04 ? '#' : '.'), \
  (byte & 0x02 ? '#' : '.'), \
  (byte & 0x01 ? '#' : '.') 


// Data and acknowledgement payloads
static uint8_t data_payload_left[NRF_GZLL_CONST_MAX_PAYLOAD_LENGTH];  ///< Placeholder for data payload received from host. 
static uint8_t data_payload_right[NRF_GZLL_CONST_MAX_PAYLOAD_LENGTH];  ///< Placeholder for data payload received from host. 
static uint8_t ack_payload[TX_PAYLOAD_LENGTH];                   ///< Payload to attach to ACK sent to device.
static uint8_t data_buffer[10];

// Debug helper variables
extern nrf_gzll_error_code_t nrf_gzll_error_code;   ///< Error code
static bool packet_received_left, packet_received_right;
uint32_t left_active = 0;
uint32_t right_active = 0;
uint8_t c;


void uart_error_handle(app_uart_evt_t * p_event)
{
    if (p_event->evt_type == APP_UART_COMMUNICATION_ERROR)
    {
        APP_ERROR_HANDLER(p_event->data.error_communication);
    }
    else if (p_event->evt_type == APP_UART_FIFO_ERROR)
    {
        APP_ERROR_HANDLER(p_event->data.error_code);
    }
}


int main(void)
{
    uint32_t err_code;
    const app_uart_comm_params_t comm_params =
      {
          RX_PIN_NUMBER,
          TX_PIN_NUMBER,
          RTS_PIN_NUMBER,
          CTS_PIN_NUMBER,
          APP_UART_FLOW_CONTROL_DISABLED,
          false,
          UART_BAUDRATE_BAUDRATE_Baud1M
      };

    APP_UART_FIFO_INIT(&comm_params,
                         UART_RX_BUF_SIZE,
                         UART_TX_BUF_SIZE,
                         uart_error_handle,
                         APP_IRQ_PRIORITY_LOW,
                         err_code);

    APP_ERROR_CHECK(err_code);

    // Initialize Gazell
    nrf_gzll_init(NRF_GZLL_MODE_HOST);

    // Addressing
    nrf_gzll_set_base_address_0(0x01020304);
    nrf_gzll_set_base_address_1(0x05060708);
  
    // Load data into TX queue
    ack_payload[0] = 0x55;
    nrf_gzll_add_packet_to_tx_fifo(0, data_payload_left, TX_PAYLOAD_LENGTH);
    nrf_gzll_add_packet_to_tx_fifo(1, data_payload_left, TX_PAYLOAD_LENGTH);

    // Enable Gazell to start sending over the air
    nrf_gzll_enable();

    // main loop
    while (true)
    {
        // detecting received packet from interupt, and unpacking
        if (packet_received_left)
        {
            packet_received_left = false;

            data_buffer[0] = ((data_payload_left[0] & 1<<7) ? 1:0) << 0 |
                             ((data_payload_left[0] & 1<<6) ? 1:0) << 1 |
                             ((data_payload_left[0] & 1<<5) ? 1:0) << 2 |
                             ((data_payload_left[0] & 1<<4) ? 1:0) << 3 |
                             ((data_payload_left[0] & 1<<3) ? 1:0) << 4 |
                             ((data_payload_left[0] & 1<<2) ? 1:0) << 5;

            data_buffer[2] = ((data_payload_left[0] & 1<<1) ? 1:0) << 0 |
                             ((data_payload_left[0] & 1<<0) ? 1:0) << 1 |
                             ((data_payload_left[1] & 1<<7) ? 1:0) << 2 |
                             ((data_payload_left[1] & 1<<6) ? 1:0) << 3 |
                             ((data_payload_left[1] & 1<<5) ? 1:0) << 4 |
                             ((data_payload_left[1] & 1<<4) ? 1:0) << 5;

            data_buffer[4] = ((data_payload_left[1] & 1<<3) ? 1:0) << 0 |
                             ((data_payload_left[1] & 1<<2) ? 1:0) << 1 |
                             ((data_payload_left[1] & 1<<1) ? 1:0) << 2 |
                             ((data_payload_left[1] & 1<<0) ? 1:0) << 3 |
                             ((data_payload_left[2] & 1<<7) ? 1:0) << 4 |
                             ((data_payload_left[2] & 1<<6) ? 1:0) << 5;

            data_buffer[6] = ((data_payload_left[2] & 1<<5) ? 1:0) << 0 |
                             ((data_payload_left[2] & 1<<4) ? 1:0) << 1 |
                             ((data_payload_left[2] & 1<<3) ? 1:0) << 2 |
                             ((data_payload_left[2] & 1<<2) ? 1:0) << 3 |
                             ((data_payload_left[2] & 1<<1) ? 1:0) << 4 |
                             ((data_payload_left[2] & 1<<0) ? 1:0) << 5;

            data_buffer[8] = ((data_payload_left[3] & 1<<7) ? 1:0) << 2 |
                             ((data_payload_left[3] & 1<<6) ? 1:0) << 3 |
                             ((data_payload_left[3] & 1<<5) ? 1:0) << 4 |
                             ((data_payload_left[3] & 1<<4) ? 1:0) << 5;

        }

        if (packet_received_right)
        {
            packet_received_right = false;

            data_buffer[1] = ((data_payload_right[0] & 1<<2) ? 1:0) << 0 |
                             ((data_payload_right[0] & 1<<3) ? 1:0) << 1 |
                             ((data_payload_right[0] & 1<<4) ? 1:0) << 2 |
                             ((data_payload_right[0] & 1<<5) ? 1:0) << 3 |
                             ((data_payload_right[0] & 1<<6) ? 1:0) << 4 |
                             ((data_payload_right[0] & 1<<7) ? 1:0) << 5;

            data_buffer[3] = ((data_payload_right[1] & 1<<4) ? 1:0) << 0 |
                             ((data_payload_right[1] & 1<<5) ? 1:0) << 1 |
                             ((data_payload_right[1] & 1<<6) ? 1:0) << 2 |
                             ((data_payload_right[1] & 1<<7) ? 1:0) << 3 |
                             ((data_payload_right[0] & 1<<0) ? 1:0) << 4 |
                             ((data_payload_right[0] & 1<<1) ? 1:0) << 5;

            data_buffer[5] = ((data_payload_right[2] & 1<<6) ? 1:0) << 0 |
                             ((data_payload_right[2] & 1<<7) ? 1:0) << 1 |
                             ((data_payload_right[1] & 1<<0) ? 1:0) << 2 |
                             ((data_payload_right[1] & 1<<1) ? 1:0) << 3 |
                             ((data_payload_right[1] & 1<<2) ? 1:0) << 4 |
                             ((data_payload_right[1] & 1<<3) ? 1:0) << 5;
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

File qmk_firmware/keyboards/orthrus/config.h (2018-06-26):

/*
Copyright 2012 Jun Wako <wakojun@gmail.com>

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
You should have received a copy of the GNU General Public License
along with this program.  If not, see <http://www.gnu.org/licenses/>.
*/

#ifndef CONFIG_H
#define CONFIG_H

#include "config_common.h"

/* USB Device descriptor parameter */

#define VENDOR_ID       0xFEED
#define PRODUCT_ID      0x6060
#define DEVICE_VER      0x0001
#define MANUFACTURER    Unknown
#define PRODUCT         Mitosis
#define DESCRIPTION     q.m.k. keyboard firmware for Mitosis

/* key matrix size */
#define MATRIX_ROWS 5
#define MATRIX_COLS 12

/* define if matrix has ghost */
//#define MATRIX_HAS_GHOST

/* number of backlight levels */
//#define BACKLIGHT_LEVELS 3

#define ONESHOT_TIMEOUT 500

#define TAPPING_TERM 200
#define PREVENT_STUCK_MODIFIERS
#define FORCE_NKRO
#define LEADER_TIMEOUT 1000


/* key combination for command */
#define IS_COMMAND() ( \
    keyboard_report->mods == (MOD_BIT(KC_LSHIFT) | MOD_BIT(KC_RSHIFT)) \
)

/*
 * Feature disable options
 *  These options are also useful to firmware size reduction.
 */

#define PREVENT_STUCK_MODIFIERS

/* disable debug print */
//#define NO_DEBUG

/* disable print */
//#define NO_PRINT

/* disable action features */
//#define NO_ACTION_LAYER
//#define NO_ACTION_TAPPING
//#define NO_ACTION_ONESHOT
//#define NO_ACTION_MACRO
//#define NO_ACTION_FUNCTION

//UART settings for communication with the RF microcontroller
#define SERIAL_UART_BAUD 1000000
#define SERIAL_UART_DATA UDR1
#define SERIAL_UART_UBRR (F_CPU / (16UL * SERIAL_UART_BAUD) - 1)
#define SERIAL_UART_TXD_READY (UCSR1A & _BV(UDRE1))
#define SERIAL_UART_RXD_PRESENT (UCSR1A & _BV(RXC1))
#define SERIAL_UART_INIT() do { \
    	/* baud rate */ \
    	UBRR1L = SERIAL_UART_UBRR; \
    	/* baud rate */ \
    	UBRR1H = SERIAL_UART_UBRR >> 8; \
    	/* enable TX and RX */ \
    	UCSR1B = _BV(TXEN1) | _BV(RXEN1); \
    	/* 8-bit data */ \
    	UCSR1C = _BV(UCSZ11) | _BV(UCSZ10); \
  	} while(0)

#endif

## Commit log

2018-06-26 moved gerbers folder
    [atreus_split-B.Cu.gbl, atreus_split-B.Mask.gbs, atreus_split-B.SilkS.gbo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]
2019-08-12 added update on battery holders

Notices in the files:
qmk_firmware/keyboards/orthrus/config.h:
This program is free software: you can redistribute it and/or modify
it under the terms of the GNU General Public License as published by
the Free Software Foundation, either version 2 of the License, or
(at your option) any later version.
